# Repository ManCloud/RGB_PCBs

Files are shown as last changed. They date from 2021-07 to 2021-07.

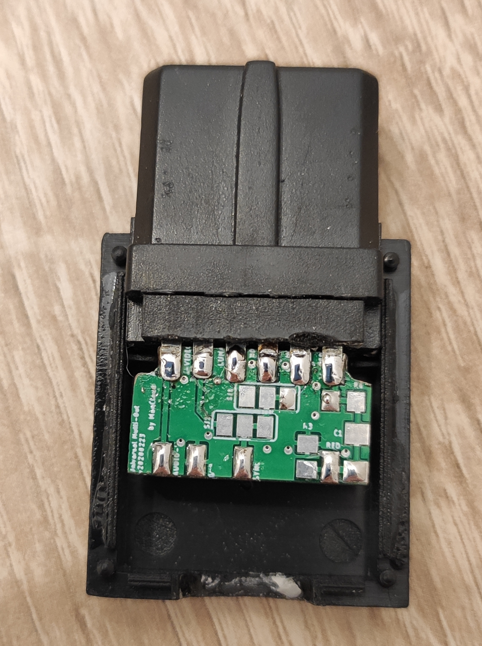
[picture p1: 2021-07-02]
pictures/IMG_20200316_200902.jpg

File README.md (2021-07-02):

# RGB-PCBs
Console video cable connector PCBs

The user [Arcade TV](https://circuit-board.de/forum/index.php/User/1861-ArcadeTV/) in the Circuit-Board community once created the first ["VSAB"s -> Vertical SCART Adaper Boards](https://circuit-board.de/forum/index.php/Thread/14997-VSAB-Vertical-Scart-Adapter-Boards-outdated/).

In 2020 he found a Post by viletim mentioning, that it's better to have the additional components on console end of the cable instead of the TV end.
So i decided to invent a PCB which would make it easier to solder these cables inspired by the VSABs but for the console end.

As the VSAB boards then no longer needed any components (alsmost) i changed them a bit as well.
 
Links to OSHPark
* Multi-Out:
  * Nintendo: 	https://oshpark.com/shared_projects/a01xTNnj
  * Sony: 		https://oshpark.com/shared_projects/g5j2vvd2
* VSAB
  * Plain: https://oshpark.com/shared_projects/fAsvh5mm
  * 75P: https://oshpark.com/shared_projects/UipCRrXt

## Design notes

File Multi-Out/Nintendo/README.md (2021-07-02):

# Nintendo
https://oshpark.com/shared_projects/a01xTNnj

## Purpose
These PCBs can be used to create cables that can be used on SNES, N64 and GameCube.

If you want to use the N64 make sure you have an RGB-modded one or you can only use CV (Composite-Video), as these boards do not support S-Video.

## Configurations
The configuraions all claim to be used with a direct wiring (e.g. with the VSAB-Plain)

### PAL-SNES
| Connection | Configuration |
| :---: | :-----: |
| SJ1/C4 | bridged |
| SJ3/C1| bridged |
| SJ4/C2| bridged |
| SJ5/C3| bridged |
| SJ2| either Luma or CV |
| R1| n.p. |
| R2| 75Ohm |
| R4| 75Ohm |
| R5| 75Ohm |
| R6| 75Ohm |

### NTSC-SNES
| Connection | Configuration |
| :---: | :-----: |
| SJ1/C4 | bridged |
| SJ3/C1| 220uF |
| SJ4/C2| 220uF |
| SJ5/C3| 220uF |
| SJ2| either Luma or CV |
| R1| n.p. |
| R2| n.p. |
| R4| n.p. |
| R5| n.p. |
| R6| n.p. |

### PAL-GameCube
| Connection | Configuration |
| :---: | :-----: |
| SJ1/C4 | 220uF |
| SJ3/C1| 220uF |
| SJ4/C2| 220uF |
| SJ5/C3| 220uF |
| SJ2| CV |
| R1| n.p. |
| R2| 75Ohm |
| R4| n.p. |
| R5| n.p. |
| R6| n.p. |

### N64
The N64 is different here. It depents on your mod which configuration you need.

E.g.: if you're using [borti4938](https://github.com/borti4938)s [N64Advanced](https://github.com/borti4938/n64rgb/tree/master/advancedRGBmod) Mod, you'd not place any part on the PCB at all:

| Connection | Configuration |
| :---: | :-----: |
| SJ1/C4 | bridged |
| SJ3/C1| bridged |
| SJ4/C2| bridged |
| SJ5/C3| bridged |
| SJ2| according to mod |
| R1| n.p. |
| R2| n.p. |
| R4| n.p. |
| R5| n.p. |
| R6| n.p. |

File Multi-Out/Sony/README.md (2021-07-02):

# Sony
https://oshpark.com/shared_projects/g5j2vvd2

## Purpose
These PCBs can be used to create cables that can be used on Playstation 1,2 and 3.

If you want to use the N64 make sure you have an RGB-modded one or you can only use CV (Composite-Video), as these boards do not support S-Video.

## Configurations
The configuraions all claim to be used with a direct wiring (e.g. with the VSAB-Plain)

### Playstation 1
| Connection | Configuration |
| :---: | :-----: |
| SJ2 | either Luma or CV |
| SJ4/C1| 220uF |
| SJ3/C2| 220uF |
| SJ1/C3| 220uF |

### Playstation 2 (3)
| Connection | Configuration |
| :---: | :-----: |
| SJ1/C4 | either Luma or CV |
| SJ3/C1| bridged |
| SJ4/C2| bridged |
| SJ5/C3| bridged |

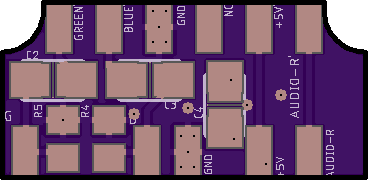
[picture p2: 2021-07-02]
Multi-Out/Nintendo/Multi-Out_N_Bottom.png

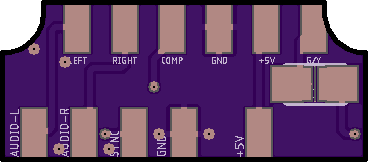
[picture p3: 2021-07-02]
Multi-Out/Sony/Multi-Out_S_Top.png

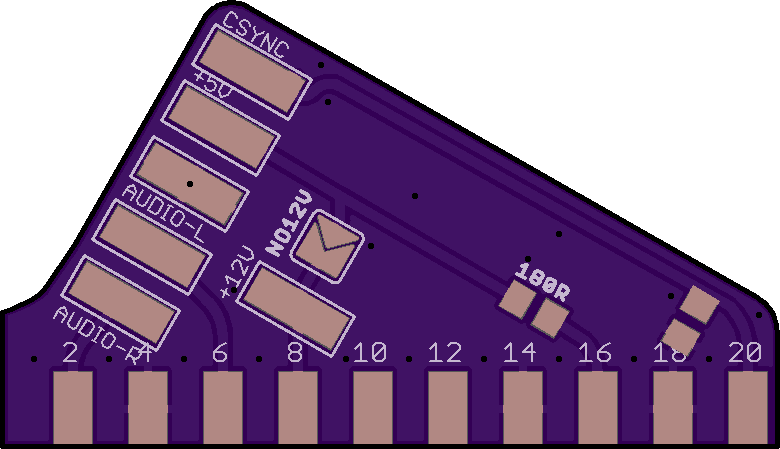
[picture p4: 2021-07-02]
VSAB/VSAB_75R_P/VSAB_75R_P_Bottom.png

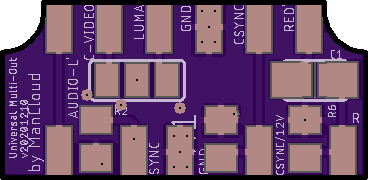
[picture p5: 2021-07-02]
Multi-Out/Nintendo/Multi-Out_N_Top.png

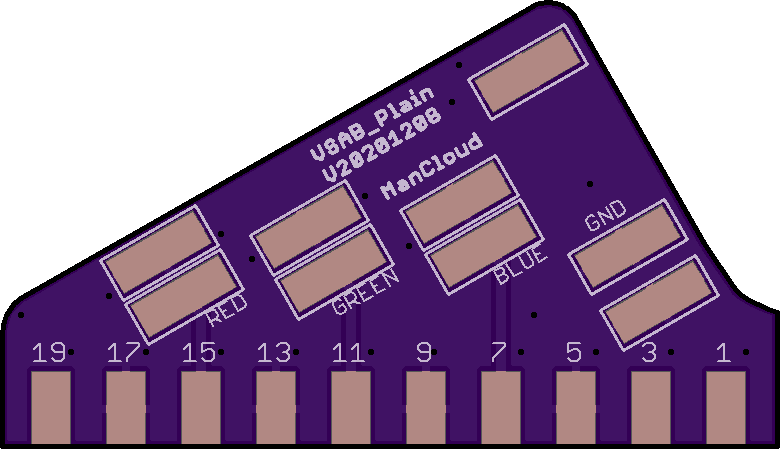
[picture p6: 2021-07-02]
VSAB/VSAB_Plain/VSAB_Plain_Top.png

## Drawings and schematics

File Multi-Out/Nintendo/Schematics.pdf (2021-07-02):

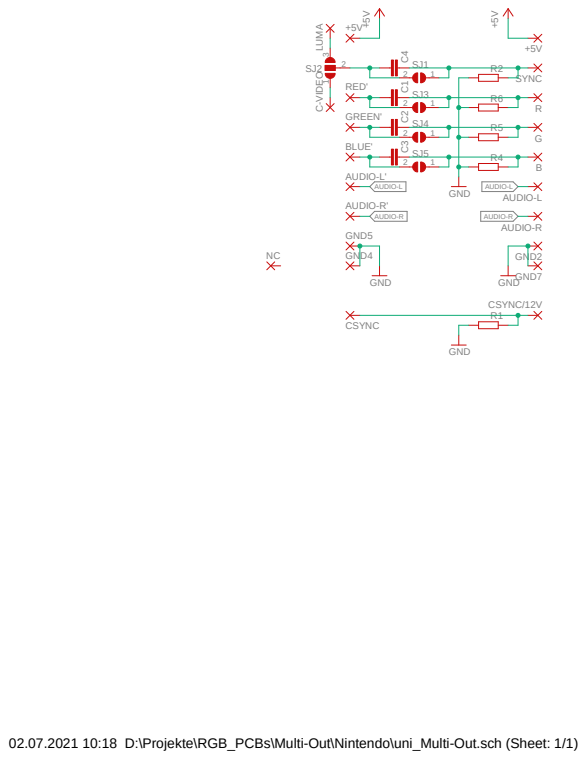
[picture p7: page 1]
02.07.2021 10:18 D:\Projekte\RGB_PCBs\Multi-Out\Nintendo\uni_Multi-Out.sch (Sheet: 1/1) ⁺⁵V; GND; B LUMA; AUDIO-L; CSYNC C⁻VIDEO; AUDIO-R; GND4; GND5; RED'; GREEN'; BLUE'; AUDIO-L'; AUDIO-R'; GND7; SYNC; GND2; CSYNC/12V

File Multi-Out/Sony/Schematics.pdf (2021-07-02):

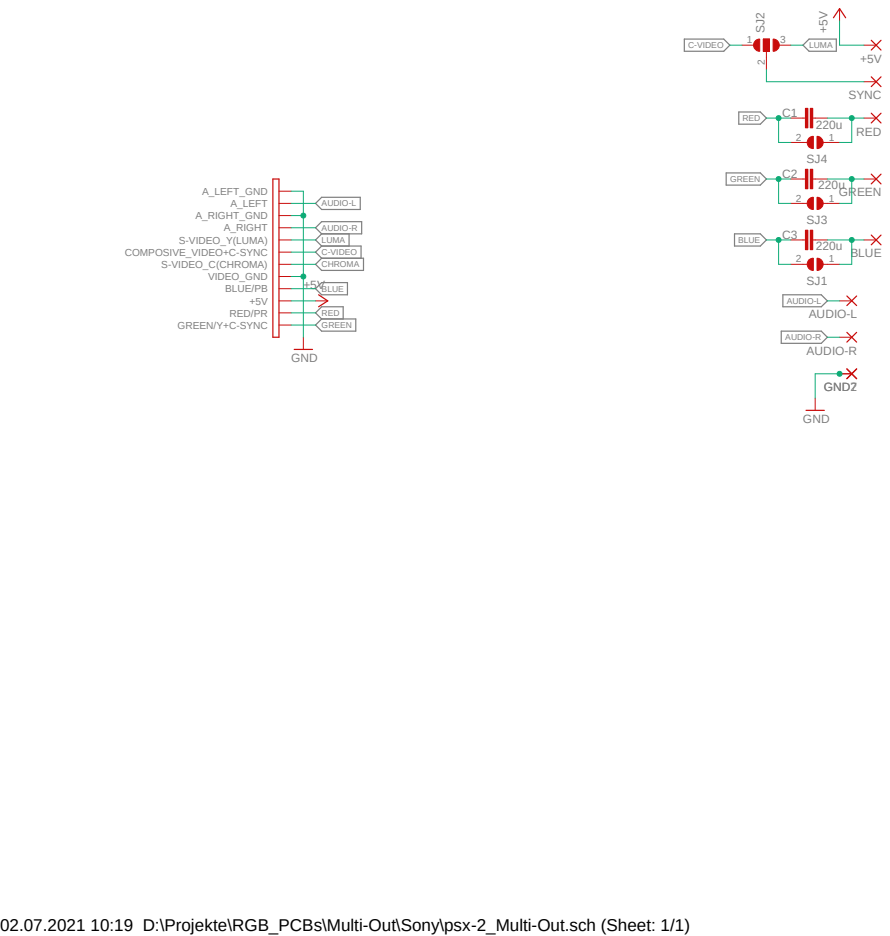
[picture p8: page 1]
GND; RED; GREEN; BLUE; AUDIO-L; AUDIO-R; GND7; SYNC; GND2; A_LEFT_GND A_LEFT A_RIGHT_GND A_RIGHT S-VIDEO_Y(LUMA) COMPOSIVE_VIDEO+C-SYNC S-VIDEO_C(CHROMA) VIDEO_GND BLUE/PB +5V; GREEN/Y+C-SYNC; RED/PR; C-VIDEO; LUMA; CHROMA

02.07.2021 10:19 D:\Projekte\RGB_PCBs\Multi-Out\Sony\psx-2_Multi-Out.sch (Sheet: 1/1)

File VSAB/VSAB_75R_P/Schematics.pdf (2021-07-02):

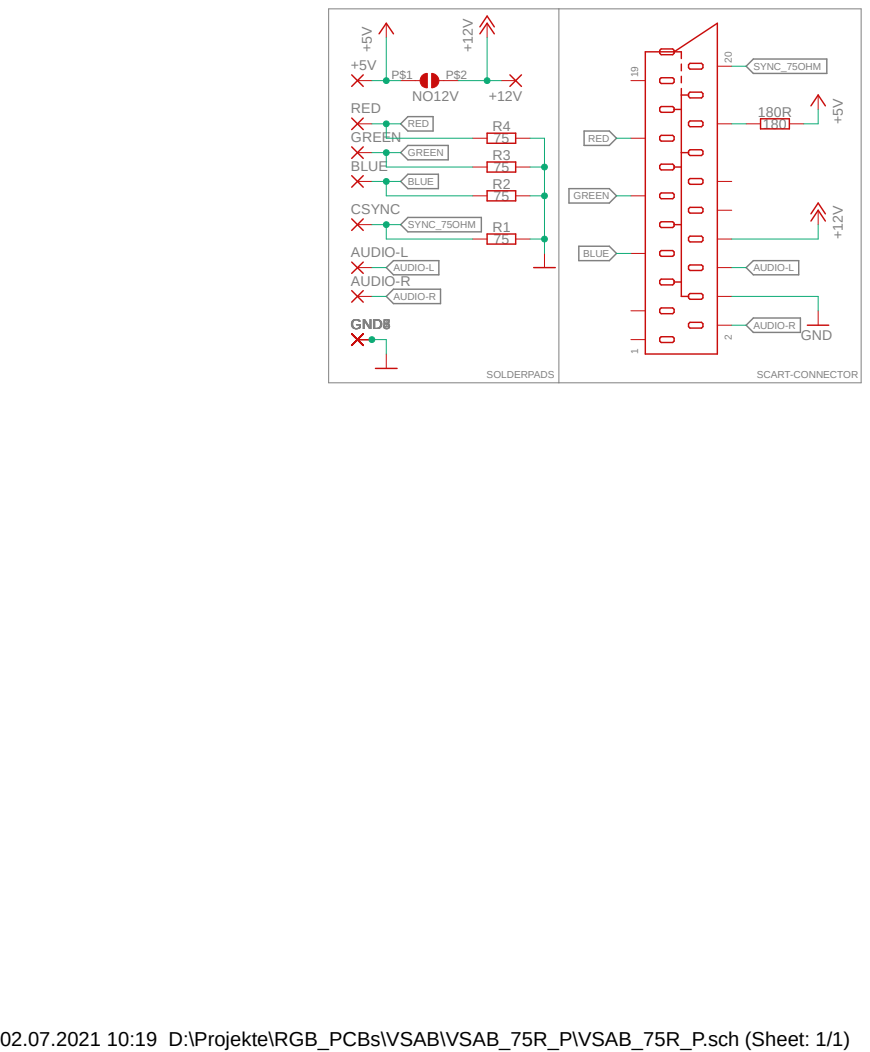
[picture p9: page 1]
SOLDERPADS; SCART-CONNECTOR ¹; GND; +12V ⁺¹²V; RED; GREEN; BLUE; CSYNC; AUDIO-L; AUDIO-R; GND3456 GND78; SYNC_75OHM

02.07.2021 10:19 D:\Projekte\RGB_PCBs\VSAB\VSAB_75R_P\VSAB_75R_P.sch (Sheet: 1/1)

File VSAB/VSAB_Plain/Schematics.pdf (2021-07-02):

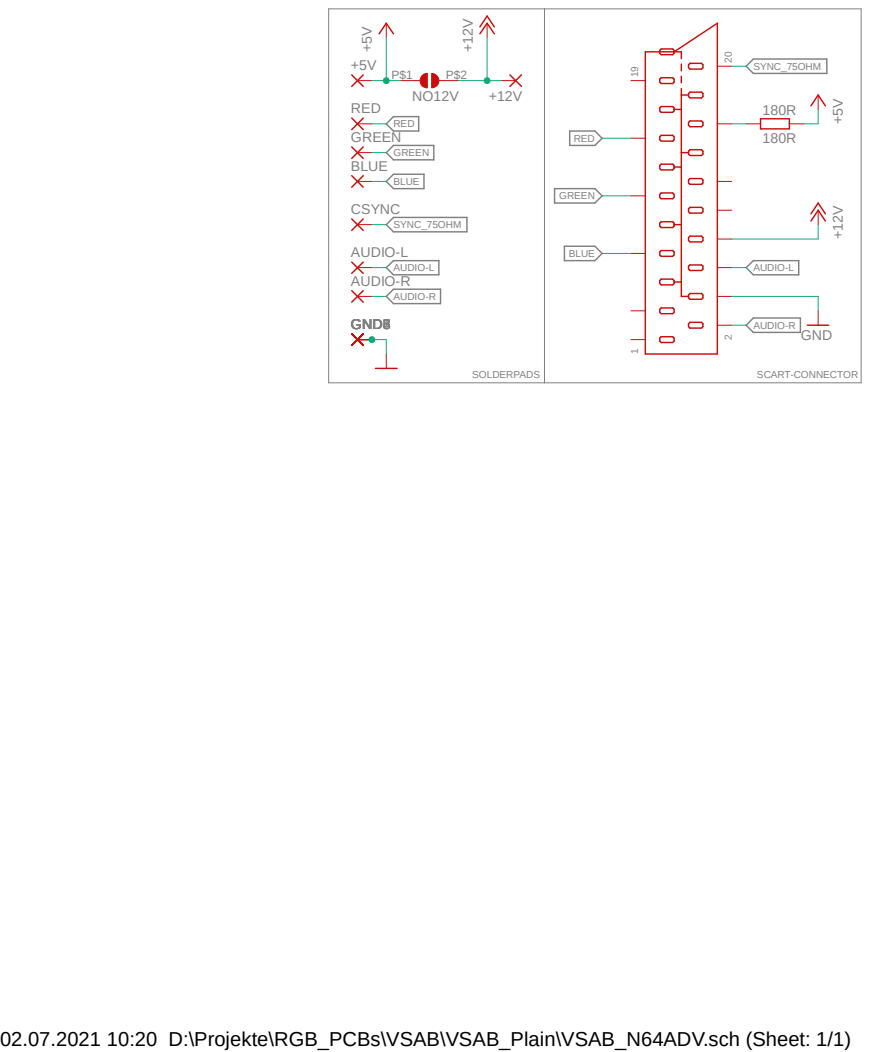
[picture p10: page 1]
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

02.07.2021 10:20 D:\Projekte\RGB_PCBs\VSAB\VSAB_Plain\VSAB_N64ADV.sch (Sheet: 1/1)

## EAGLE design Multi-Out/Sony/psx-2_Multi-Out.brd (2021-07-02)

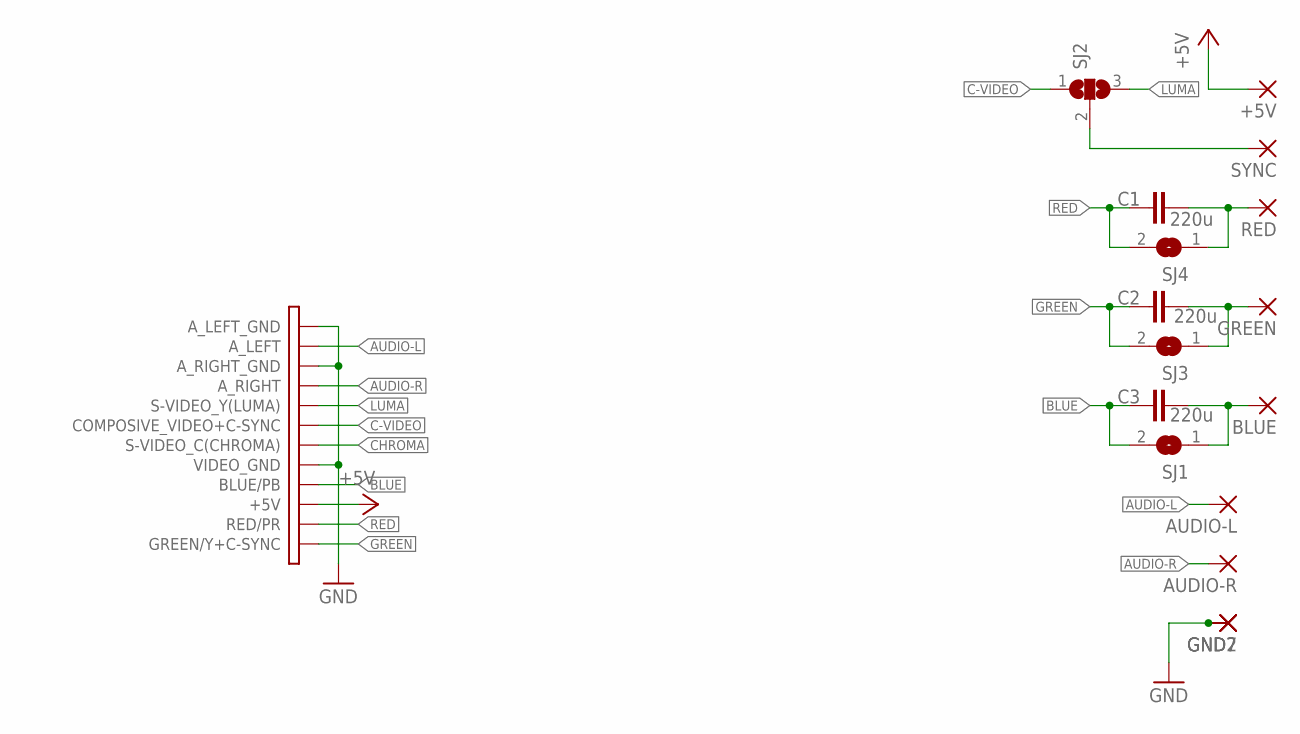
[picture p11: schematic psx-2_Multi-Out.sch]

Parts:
+5V: WIREPADSMD1,27-254; SMD1,27-2,54
AUDIO-L: WIREPADSMD1,27-254; SMD1,27-2,54
AUDIO-R: WIREPADSMD1,27-254; SMD1,27-2,54
BLUE: WIREPADSMD1,27-254; SMD1,27-2,54
C1, C2, C3: 220u; C1206
GND2, GND7: WIREPADSMD1,27-254; SMD1,27-2,54
GREEN: WIREPADSMD1,27-254; SMD1,27-2,54
J1: PS/2_MULTI-AV
RED: WIREPADSMD1,27-254; SMD1,27-2,54
SJ1, SJ3, SJ4: SJ
SJ2: SJ2W; SJ_2
SYNC: WIREPADSMD1,27-254; SMD1,27-2,54

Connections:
+5V: +5V.1, J1.+5V
AUDIO-L: AUDIO-L.1, J1.A_LEFT
AUDIO-R: AUDIO-R.1, J1.A_RIGHT
BLUE: C3.1, J1.BLUE/PB, SJ1.2
BLUE'': BLUE.1, C3.2, SJ1.1
C-VIDEO: J1.COMPOSITE_VIDEO+C-S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 (COMPOSIVE_VIDEO+C-SYNC), SJ2.1
CHROMA: J1.S-VIDEO_C(CHROMA)
GND: GND2.1, GND7.1, J1.A_LEFT_GND, J1.A_RIGHT_GND, J1.VIDEO_GND
GREEN: C2.1, J1.GREEN/Y+C-SYNC, SJ3.2
GREEN'': C2.2, GREEN.1, SJ3.1
LUMA: J1.S-VIDEO_Y(LUMA), SJ2.3
RED: C1.1, J1.RED/PR, SJ4.2
RED'': C1.2, RED.1, SJ4.1
SYNC: SJ2.2, SYNC.1

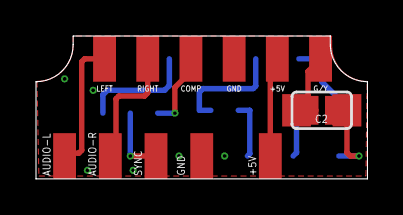
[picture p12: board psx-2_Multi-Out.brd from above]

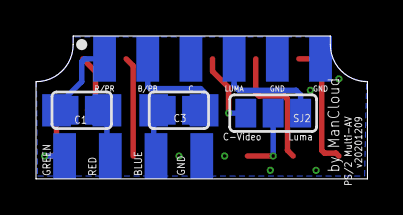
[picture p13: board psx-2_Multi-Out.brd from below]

Board: 2 copper layers, 18.4 x 7.9 mm, 17 parts (9 on the bottom side), 13 nets.

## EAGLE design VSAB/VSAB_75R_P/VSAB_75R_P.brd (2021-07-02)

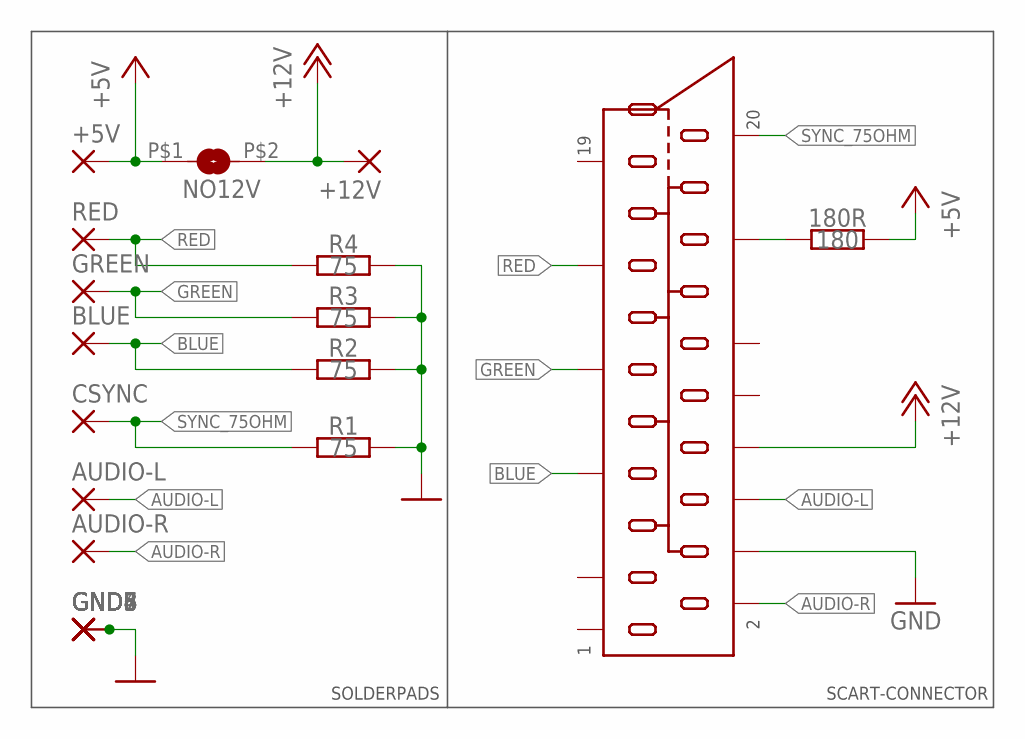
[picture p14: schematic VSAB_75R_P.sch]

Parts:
180R: 180; R0805
+5V, +12V: WIREPADSMD5-1,8; 5-1,8
AUDIO-L: WIREPADSMD5-1,8; 5-1,8
AUDIO-R: WIREPADSMD5-1,8; 5-1,8
BLUE: WIREPADSMD5-1,8; 5-1,8
CSYNC: WIREPADSMD5-1,8; 5-1,8
GND, GND3, GND4, GND5, GND6, GND7, GND8: WIREPADSMD5-1,8; 5-1,8
GREEN: WIREPADSMD5-1,8; 5-1,8
NO12V: MY_JUMPER; MYJUMP
R1, R2, R3, R4: 75; R0805
RED: WIREPADSMD5-1,8; 5-1,8
U$2: SCART_PLUG; SCART

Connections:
+5V: 180R.1, +5V.1, NO12V.P$1 (1)
+5V': 180R.2, U$2.16 (AV/RGB_SW)
+12V: +12V.1, NO12V.P$2 (2), U$2.8 (TV/AV_SW)
AUDIO-L: AUDIO-L.1, U$2.6 (AUDIO_IN_L)
AUDIO-R: AUDIO-R.1, U$2.2 (AUDIO_IN_R)
BLUE: BLUE.1, R2.2, U$2.7 (RGB_BLUE/YUV_V/PB)
GND: GND.1, GND3.1, GND4.1, GND5.1, GND6.1, GND7.1, GND8.1, R1.1, R2.1, R3.1, R4.1, U$2.4 (GND), U$2.5 (GND), U$2.9 (GND), U$2.13 (GND), U$2.14 (GND), U$2.17 (GND), U$2.18 (GND)
GREEN: GREEN.1, R3.2, U$2.11 (RGB_GREEN/YUV-Y)
RED: R4.2, RED.1, U$2.15 (RGB_RED/YUV-U/PR/CHROMA)
SYNC_75OHM: CSYNC.1, R1.2, U$2.20 (COMP/SYNC/LUMA_IN)

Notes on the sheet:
SOLDERPADS
SCART-CONNECTOR

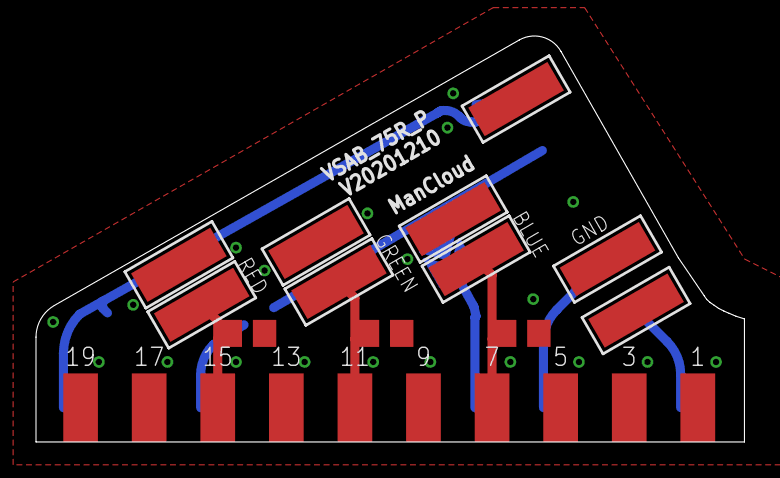
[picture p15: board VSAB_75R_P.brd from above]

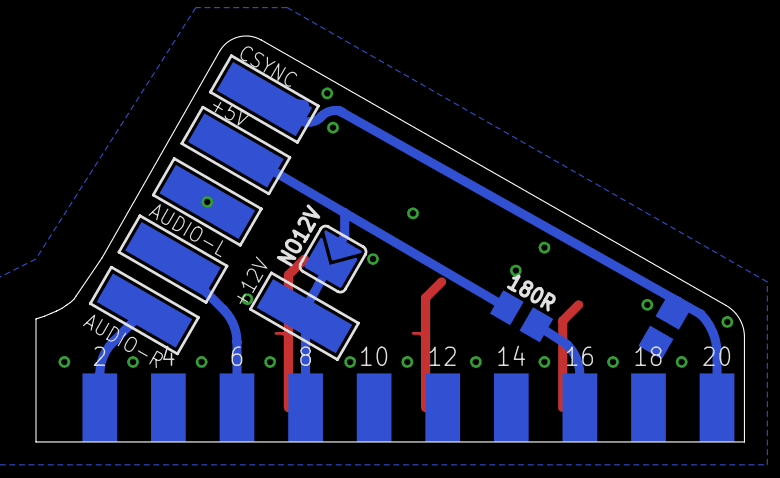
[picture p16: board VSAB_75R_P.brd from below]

Board: 2 copper layers, 39.4 x 22.6 mm, 22 parts (9 on the bottom side), 10 nets.

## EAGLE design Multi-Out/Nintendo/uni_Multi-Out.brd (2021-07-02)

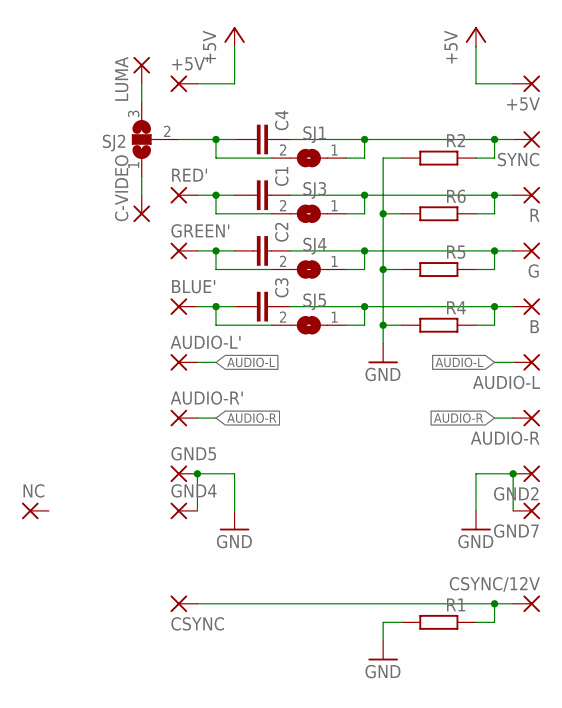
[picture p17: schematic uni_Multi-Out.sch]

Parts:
+5V, +5V': WIREPADSMD1,27-254; SMD1,27-2,54
AUDIO-L: WIREPADSMD1,27-254; SMD1,27-2,54
AUDIO-L': WIREPADSMD1,27-254; SMD1,27-2,54
AUDIO-R: WIREPADSMD1,27-254; SMD1,27-2,54
AUDIO-R': WIREPADSMD1,27-254; SMD1,27-2,54
B: WIREPADSMD1,27-254; SMD1,27-2,54
BLUE': WIREPADSMD1,27-254; SMD1,27-2,54
C1, C2, C3, C4: C-EUC1206; C1206
C-VIDEO: WIREPADSMD1,27-254; SMD1,27-2,54
CSYNC: WIREPADSMD1,27-254; SMD1,27-2,54
CSYNC/12V: WIREPADSMD1,27-254; SMD1,27-2,54
G: WIREPADSMD1,27-254; SMD1,27-2,54
GND2, GND4, GND5, GND7: WIREPADSMD1,27-254; SMD1,27-2,54
GREEN': WIREPADSMD1,27-254; SMD1,27-2,54
LUMA: WIREPADSMD1,27-254; SMD1,27-2,54
NC: WIREPADSMD1,27-254; SMD1,27-2,54
R: WIREPADSMD1,27-254; SMD1,27-2,54
R1, R2, R4, R5, R6: R-EU_R0805; R0805
RED': WIREPADSMD1,27-254; SMD1,27-2,54
SJ1, SJ3, SJ4, SJ5: SJ
SJ2: SJ2W; SJ_2
SYNC: WIREPADSMD1,27-254; SMD1,27-2,54

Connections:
+5V: +5V.1, +5V'.1
AUDIO-L: AUDIO-L.1, AUDIO-L'.1
AUDIO-R: AUDIO-R.1, AUDIO-R'.1
BLUE': B.1, C3.1, R4.1, SJ5.1
BLUE'': BLUE'.1, C3.2, SJ5.2
C-VIDEO: C-VIDEO.1, SJ2.1
CSYNC/+12V: CSYNC.1, CSYNC/12V.1, R1.1
GND: GND2.1, GND4.1, GND5.1, GND7.1, R1.2, R2.2, R4.2, R5.2, R6.2
GREEN': C2.1, G.1, R5.1, SJ4.1
GREEN'': C2.2, GREEN'.1, SJ4.2
LUMA: LUMA.1, SJ2.3
unnamed: C4.2, SJ1.2, SJ2.2
RED': C1.1, R.1, R6.1, SJ3.1
RED'': C1.2, RED'.1, SJ3.2
SYNC: C4.1, R2.1, SJ1.1, SYNC.1

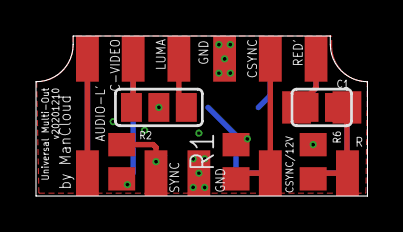
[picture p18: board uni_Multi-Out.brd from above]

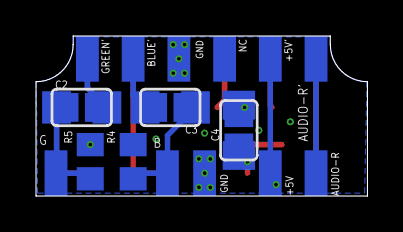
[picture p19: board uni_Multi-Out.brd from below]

Board: 2 copper layers, 18.4 x 8.9 mm, 36 parts (19 on the bottom side), 15 nets.
